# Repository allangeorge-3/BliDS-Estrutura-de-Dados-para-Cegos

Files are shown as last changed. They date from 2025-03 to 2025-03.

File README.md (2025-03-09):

# BlinDS-Estrutura-de-Dados-para-Cegos
Material Educacional de Estrutura de Dados para pessoas com deficiência visual. Contém: Modelos 3D para impressão das peças do material tátil; um Guia de Uso; 2 Sequências Didáticas de apoio ao professor; Familiarização com o material, Pilha e Árvore Binária. Produto da pesquisa de Allan George Bezerra no Mestrado em Tecnologia Educacional - UFC

Produto educacional doMestrado Profissional em Tecnologia Educacional de Allan George Bezerra, da Universidade Federal do Ceará.
Os modelos tridimensionais estãodisponíveis para impressão em uma impressora 3D. O produto da pesquisa passou por 4 versões. A versão 4 do material tátil foiescolhida para seravaliada e foi bem recebida por alunos com deficiência visual e professores de Estrutura de Dados.
Os modelos das versões anteriores também estão disponíveis.

********
IMPRESSÃO DO MATERIAL

Indicado verificar o Guia de Uso do material para saber os componentes básicos de um conjunto para estudo de Estrutura de Dados por pessoas com deficiência visual.
- A base de 8 folhas pode ser montada somente com o encaixe das peças menores. Entretanto, é indicado que essas peças sejam coladas com supercola, para garantir a firmeza durante o uso;
- Fazer o mesmo com a Raiz Conectora, que é formada por 3 peças menores. Colar as 3, formando uma peça única;
- - Pintar os números em relevo (braille e tinta) e as ligações/arestas entre os espaços para encaixes nas bases. Usar uma cor que contrastefortemente com o plano de fundo dessas peças (se o filamento for branco, usar tinta preta, se o filamento for azul-escuro, usar amarelo ou branco, por exemplo).

O link paradissertação do mestrado será disponibilizada após a defesa.

O uso, distribuição e alteração do material é permitido, desde queo link deste projeto seja citado como fonte original.

Contato: allangeorge.3@gmail.com, allangeorge@virtual.ufc.br.
Instagram: allangeorge.3

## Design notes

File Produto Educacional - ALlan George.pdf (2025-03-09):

### 7 O PRODUTO EDUCACIONAL

Complementando os resultados da Etapa 7, este capítulo apresenta a Versão

4 do material tátil, o guia de uso e as duas sequências didáticas. Eles compõem o artefato

que passou pela avaliação descrita no Capítulo 8.

O | produto | está | disponível | no | link:

https://1drv.ms/f/s!Ahwq801rHAGvhtkIIQJfQrJ9wTQ3Ow?e=lKW3Xw

### 7.1 Guia de Uso do Material Tátil

Para apresentar o material tátil ao aluno com DV, ou ao professor, foi elaborado um guia de uso (APÊNDICE F) contemplando uma explicação sobre o seu

objetivo, especificação e descrição das peças, orientação sobre o preparo do material para

iniciar os estudos de ED, e algumas dicas de utilização.

O documento é digital, no formato PDF, e contém algumas imagens para

facilitar ao professor na compreensão do material e seu uso, especialmente se for preciso

acompanhar o discente com DV na familiarização com o material tátil.

### 7.2 Sequências Didáticas

Segundo Zabala (1998, p. 14), temos a seguinte definição para as sequências

didáticas: “são um conjunto de atividades ordenadas, estruturadas e articuladas para a

realização de certos objetivos educacionais, que têm um princípio e um fim conhecidos

tanto pelos professores como pelos alunos.”.

As sequências didáticas desenvolvidas nesta pesquisa também compõem o

artefato. Elas contêm a lista de passos para o desenvolvimento integral das atividades

propostas. O texto se preocupa com a compreensão dos professores que acompanharão a

execução das atividades, e nos alunos com DV que necessitarão de instruções claras para

o entendimento do conteúdo e a manipulação do material tátil.

As sequências são de fácil compreensão, com as etapas descritas em textos

diretos, além de expor claramente seus objetivos e tipo de atividade proposta,

contemplando as fases de planejamento, aplicação e avaliação (Zabala, 1998).

As duas sequências didáticas elaboradas nesta pesquisa podem ser consultadas nos APÊNDICE G E APÊNDICE H, e o detalhamento sobre seu

desenvolvimento estão na subseção a seguir:

### 7.2.1 Especificação das Sequências Didáticas

A fim de facilitar o processo de adaptação das aulas para incluir alunos com

deficiência visual, especialmente para os professores sem experiência ou formação com

educação especial, criou-se um modelo de sequência contendo seções de Planejamento,

Aplicação das atividades e Avaliação. Elas foram exportadas no formato PDF, permitindo

o acesso dos professores e dos alunos que utilizam algum leitor de tela.

A partir dos resultados do questionário com os Professores Consultores, pensou-se em duas sequências didáticas, S1 (APÊNDICE G) e S2 (APÊNDICE H). S1

aborda a familiarização do aluno com DV com o material tátil, propondo que o professor

tenha um contato particular com o estudante, possibilitando que se compreenda mais

sobre os conhecimentos prévios, habilidades e eventuais dificuldades do discente. Além

disso, o discente poderá conhecer o material, e combinar com o professor como será a

comunicação sobre o seu uso, o que é essencial para que o docente possa orientá-lo nas

atividades durante as aulas.

Também há uma atividade com a estrutura de dados Pilha, com dicas de uso

do material para trabalhar estruturas lineares. Isso será útil para preparar o discente no

estudo de vetores, e nas aulas da primeira parte da disciplina de ED.
A sequência S2 (APÊNDICE H) foca na estrutura Árvore Binária,

trabalhando alguns conceitos e a execução de três algoritmos: Inserção, Remoção e Pré-

Ordem. Esta segunda sequência tem mais direcionamentos para o professor, na etapa de

Planejamento. Algumas orientações sobre a verbalização do que é escrito no quadro,

descrição de imagens e comunicação com o aluno com DV, para que haja sincronia entre

a área da estrutura que o professor está apresentando no quadro ou projeções, e a área da

estrutura tateada pelo aluno no material.

Esta segunda sequência permite o uso do material em sua completude, além

trabalhar exigir uma maior interação com o material, na identificação de todas as áreas de

encaixe de números, e a manipulação constante dessas peças e das caixas organizadoras.

A execução dos algoritmos serve para mostrar o potencial do material tátil, visto que

muitas atividades e avaliações analisam o aprendizado do aluno acerca da execução

desses métodos.

O tempo previsto para cada sequência foi sugerido a partir de testes feitos

pelo próprio pesquisador. Ficando 50 minutos para S1, e 110 minutos para S2. Como S2 tem um conteúdo mais extenso, também se propôs dividir a atividade em duas aulas de

50 a 60 minutos.

A aplicação da sequência conta com vários passos, orientando pequenas ações

até que se cumpra uma atividade proposta. Alguns passos contêm dicas de orientação ao

aluno com deficiência visual, inclusive no uso do material tátil.

As avaliações propostas permitem que o discente possa exercitar o conteúdo

abordado, além de permitir que o professor identifique se o aluno conseguiu assimilá-lo.

Por fim, a sequência também aponta o que se espera sobre o aprendizado do aluno, sobre

o que foi abordado.

### 7.3 Versão 4 do Material Tátil

Após as análises dos pontos negativos da Versão 3 do material tátil, pensou-

se em uma nova modelagem que melhorasse alguns requisitos: Estabilidade física do

material, Facilidade de Manuseio, Facilidade de Compreensão e Compatibilidade com

ED.

Melhorando a estabilidade física, facilidade de manuseio e a facilidade de

compreensão, optou-se por abandonar as peças destacáveis para representar as conexões

entre os nós, e trocando seu respectivo espaço de encaixe em baixo relevo, por ligações

fixas em alto relevo. Apesar de possibilitar a presença de conexões entre encaixes e nós

vazios, considerou-se esta opção mais vantajosa do que a instabilidade de peças soltando,

como ocorria na Versão 3.

As ligações entre nós de níveis diferentes ficaram mais longas, ampliando o

comprimento do material, mas ainda permitindo que ele possa ser utilizado em uma

pequena mesa.

A nova base recebeu o nome de “Base de 8 folhas”, pois o último nível

contém oito espaços para encaixe de números em sequência. Ela possui 40cm de largura

e 32,5cm de altura. A seguir, a Figura 21 mostra a nova base:

Figura 21 – Base de 8 Folhas

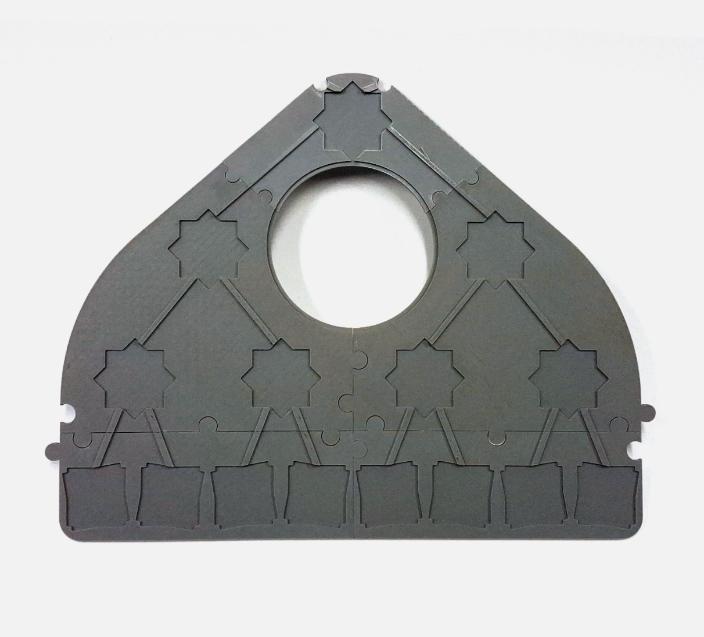
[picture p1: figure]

Fonte: Foto tirada por colaboradores do autor.

O requisito Compatibilidade com Estrutura de Dados foi melhorado com a

criação de uma peça chamada “Raiz Conectora”. Seu papel é servir como uma raiz de

uma árvore binária com 5 níveis. Esta peça pode ser encaixada nos topos de duas bases

de 8 folhas conectadas uma ao lado da outra. A Figura 22 mostra a Raiz Conectora:

Figura 22 – Raiz Conectora

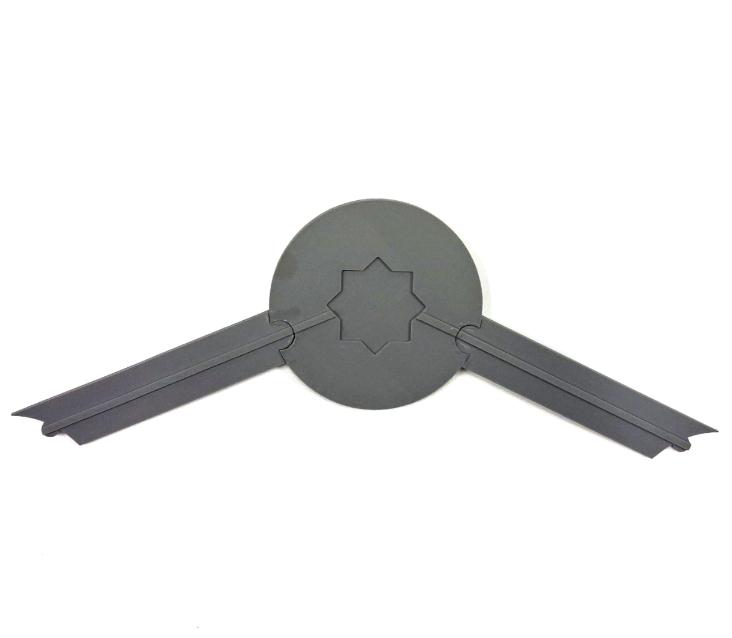
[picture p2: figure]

Fonte: Foto tirada por colaboradores do autor.
A Figura 23 mostra uma grande base formada pela união de duas bases de 8

folhas, uma ao lado da outra, com a raiz conectora no topo das duas. Essa montagem se

chama “Base de 16 folhas”, pois o último nível contém uma sequência de 16 espaços

para encaixe de números, além de ter cinco níveis. Essa montagem completa tem 80cm

de largura e 44,5cm de altura.

Figura 23 – Montagem da Base de 16 Folhas

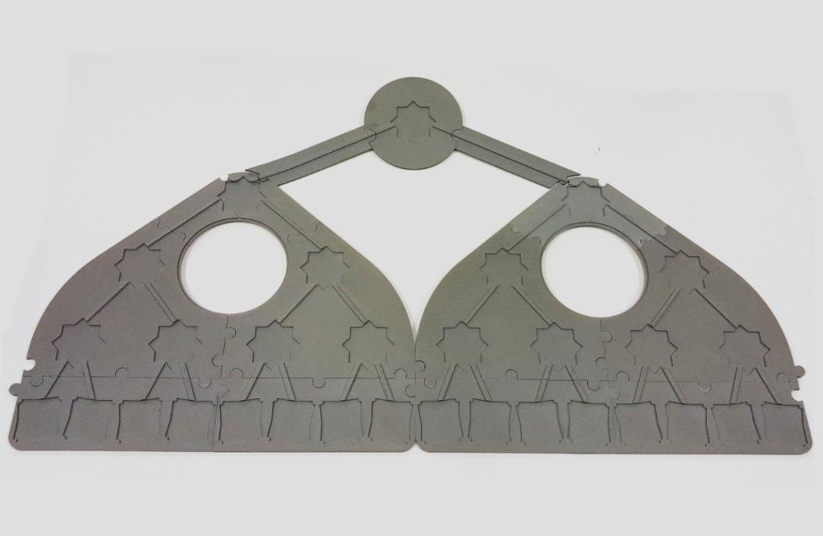
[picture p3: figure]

Fonte: Foto tirada por colaboradores do autor.
Buscando melhorar ainda mais a facilidade de manuseio, com foco na

agilidade do uso do material para realizar as atividades, foram criadas as “Caixas

Organizadoras”. Elas foram pensadas para guardar os números de forma ordenada,

permitindo que o discente com DV encontre a peça numérica rapidamente.

Elas possuem sete espaços para encaixe de números, sendo dois deles um

pouco separados dos demais. O guia de apresentação indica que os números sejam

organizados de cinco em cinco, para que o cálculo mental feito pelo usuário para

identificar a caixa que contém o número procurado seja simples. Os dois espaços

adicionais foram pensados para inserir números repetidos, caso se opte por imprimir

duplicatas.

A Figura 24 mostra algumas caixas organizadoras, algumas com números

encaixados e outras vazias:

Figura 24 – Caixas organizadoras

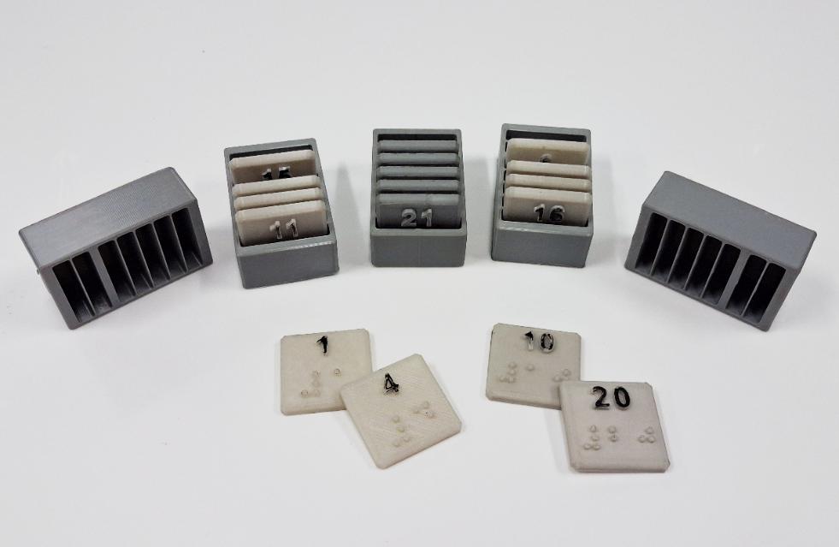
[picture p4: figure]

Fonte: Foto tirada por colaboradores do autor.

Uma última mudança, buscando melhorar o requisito de Compatibilidade

com Estrutura de Dados, foi a mudança no espaço para encaixe dos números. Agora, ela

também permite que uma peça numérica seja encaixada de uma forma alternativa à

anterior. Bastando rotacionar um pouco a peça numérica, é possível encaixá-la em uma

posição diferente. Isso permite que alguns conceitos mais avançados sejam trabalhados, como a pintura dos nós no conteúdo de Árvore Rubro-Negra. Nas entrevistas com os

Alunos Consultores, houve falas sobre a grande dificuldade de compreensão deste

conteúdo, por isso se pensou em adicionar esta funcionalidade ao material.

O guia de uso indica a área da superfície mínima para um uso confortável do

material tátil, já pensando na base completa de 16 folhas, mais um espaço para posicionar

as caixas organizadoras. Uma mesa de 90cm de largura por 50cm de comprimento é o

suficiente para trabalhar com essa estrutura mais completa. Entretanto, se a atividade

puder ser executada somente com uma base de 8 folhas, uma superfície menor pode ser

utilizada. A Figura 25 apresenta uma sugestão de configuração do ambiente de estudo

com o material completo:

Figura 25 – Base de 16 Folhas e as Caixas organizadoras com os números

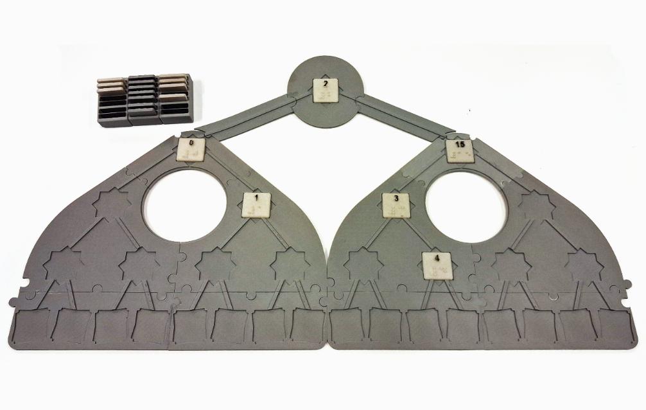
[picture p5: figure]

Fonte: Foto tirada por colaboradores do autor.

A base de 8 folhas é formada por peças menores que se conectam entre si a

partir de encaixes semelhantes aos de um quebra-cabeça, da mesma forma acontece com

a raiz conectora. Pensou-se na versatilidade e na redução da complexidade de replicação,

visto que não se precisaria mais colar essas peças menores. Entretanto, perdeu-se muito

na estabilidade física do material, pois alguns encaixes se soltavam quando as peças eram

movimentadas na superfície, e na facilidade de manuseio, pois a montagem de uma única

base exigia muito tempo e esforço. Por isso, optou-se por colar as peças menores,

transformando-as em componentes maiores, como os já citados.

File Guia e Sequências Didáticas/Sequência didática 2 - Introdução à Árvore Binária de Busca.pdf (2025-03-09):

SEQUÊNCIA DIDÁTICA

DISCIPLINA: Estrutura de Dados

Especificação: Sequência didática utilizando material tátil acessível para pessoas com deficiência visual.

Autor: Allan George Bezerra (allangeorge@virtual.ufc.br )

Instituição: Universidade Federal do Ceará – Mestrado Profissional em Tecnologia Educacional (ppgte.ufc.br)

TEMA: Introdução à Árvore Binária de Busca, usando o material tátil.

CONTEÚDOS TRABALHADOS

- Representação de uma árvore binária no material tátil.
- Trabalhar no desenho da Árvore Binária os conceitos: Raiz, folha, subárvore e altura.
- Execução dos algoritmos de Inserção e Remoção em uma Árvore Binária de Busca.
- Execução do algoritmo para percorrer uma Árvore Binária de Busca em Pré-Ordem.

HABILIDADES

- O aluno aprenderá como utilizar o material tátil para construir a estrutura de dados Árvore Binária de Busca. Ele será orientado sobre a utilização das peças e como tatear o material para compreender o desenho geral da estrutura, assim como os elementos que a compõem.
- O discente saberá identificar alguns conceitos da estrutura de dados Árvore Binária, através do desenho formado no material tátil, tais como: Raíz, nó folha, subárvore e altura.
- O discente aprenderá a construir uma Árvore Binária de Busca utilizando o método de Inserção, e poderá fazer alterações com o método de Remoção de elementos.
- O discente aprenderá a percorrer a árvore utilizando o algoritmo de Pré-Ordem. Ficando apto a percorrer, também, com os algoritmos de Pós-Ordem e Em Ordem.

Tempo da sequência didática

Cerca de 110 minutos.

Caso queira dividir em duas aulas:

Aula 1 – Partes 1 e 2: 60 minutos;

Aula 2 – Partes 3 e 4: 60 minutos.

Materiais necessários para a sequência didática

- Material educacional tátil completo: 5 Caixas organizadoras, Números de 1 a 20, 2 Bases de 8 folhas e Raiz conectora;
- Mesa com superfície de pelo menos 90cm de comprimento e 50cm de largura, aproximadamente;
- Computador equipado com leitor de tela, celular ou outro meio acessível para o aluno fazer anotações ou ler materiais enviados pelo professor.

AULA

Organização

É importante que os alunos com deficiência visual tenham uma mesa com superfície de tamanho suficiente para comportar o material com conforto. Se ele precisar utilizar o computador, é importante que esta mesa esteja bem próxima para que ele possa se mover facilmente e acessar algo.

O material tátil será utilizado para “desenhar” a estrutura de Dados Árvore Binária, da mesma forma que os demais alunos irão desenhar ou observar na lousa os desenhos visuais. Portanto, espera-se que o discente com deficiência visual seja capaz de acompanhar os desenhos pelo material montado, assim como fazer ou responder aos questionamentos feitos durante a aula.

Quando o professor for ministrar os conteúdos propostos nesta Sequência Didática, total ou em partes, é indicado que seja descritivo em suas ações, como:

- Ao escrever na lousa, ditar tudo que está escrevendo;
- Ao apresentar slides, descrever o conteúdo das imagens, e, se importante for, ler o conteúdo projetado;
- Quando for utilizar o desenho de uma Árvore Binária para os exemplos, passe a sequência de números para os alunos com deficiência visual que estarão utilizando o material tátil. Se eles já souberem executar o algoritmo de Inserção, eles saberão construir a árvore a partir da sequência informada. O ideal é que a sequência seja informada ao discente com deficiência visual, antes de desenhar a imagem, ou, caso ela já esteja pronta no slide, você pode preparar um documento digital acessível com antecedência, contendo a lista de sequências numéricas para montagem das árvores. No momento da aula, bastará informar qual a sequência de números que o discente deverá utilizar. Ele poderá acessar o documento de texto pelo celular ou computador.

- Caso o desenho da árvore seja improvisado, ou seja, no momento da aula, o professor poderá executar rapidamente o algoritmo que percorre a árvore em pré-ordem. A sequência numérica resultante poderá ser repassada para o aluno por e-mail ou formato digital que o permita acessar pelo celular ou computador. A árvore binária resultante da inserção dos elementos dessa sequência será igual a que o professor desenhou improvisadamente.
- Quando for apontar um elemento na árvore, além de dizer o valor do nó, é importante descrever sua posição de forma clara e sucinta. Algumas sugestões são: “O nó raiz com valor 18”, “Aqui, no terceiro nível, o quarto nó da esquerda para direita, de valor 10”, “Descendo para a esquerda, temos o nó X” ou “No nível 4 da árvore, o segundo nó, de valor 2, é um nó folha” (se já acertar com o aluno que a contagem de nós é da esquerda para direita, não precisará informar que se deve contar nessa direção, pois já fica subtendido).

Introdução

A aula ocorrerá normalmente, para toda a turma, incluindo o discente com deficiência visual. Ele já deve estar posicionado com o material montado. O professor deve verificar se o aluno precisará montar a base completa de 16 folhas, ou se apenas uma Base de 8 folhas já é o suficiente para todos os exemplos a serem trabalhados na aula.

Com a aula descritiva, tendo as informações passadas ao aluno com deficiência visual antecipadamente, e dando um acesso fácil e ágil ao dispositivo preferível por ele (celular, computador, notebook etc.), espera-se que a aula siga sem a necessidade de mais adaptações, além das citadas anteriormente.

Caso o professor organize o seu cronograma de aulas de forma incompatível a esta sequência didática, ele pode fazer uma divisão dos conteúdos, trabalhando as partes 1 e 2 em uma aula, e as partes 3 e 4 em um outro momento.

Desenvolvimento

Parte 1: Construindo uma Árvore Binária

1- Construa uma Árvore Binária no material tátil.

O discente deve colocar as peças numéricas nos encaixes na Base de 8 folhas. Por ser uma peça mais simples e compacta, o entendimento do desenho da estrutura será mais fácil. Aproveite para desenhar na lousa a mesma estrutura de árvore que o discente com deficiência visual está montando na base.

O encaixe deve seguir uma ordem: Iniciando pelo encaixe do primeiro nível, depois os encaixes no segundo nível. Quando preencher todos os espaços, o discente poderá passar para o próximo nível. O último nível (nível 4) não precisa ser totalmente preenchido.

2- Compreenda o desenho de uma Árvore Binária.

O discente deve utilizar as mãos para sentir as peças encaixadas, e perceber as ligações entre um número e o outro encaixado logo abaixo. Se quiser, pode usar uma das mãos para percorrer, e a outra para segurar a base através do círculo vazado, caso queira manter o material mais firme.

O professor pode verbalizar todos os elementos da árvore, informando o caminho que está percorrendo ("A raiz é o número X, descendo pela esquerda temos o nó Y, indo a esquerda novamente, temos o número Z"). Outra opção é pedir que o próprio aluno com deficiência visual verbalize os nós visitados e os caminhos que vai percorrendo, conforme a orientação do professor (“Segue para o nó raiz. Qual o valor dele? Descendo pelo caminho a esquerda, qual o valor desse nó?” etc.).

Cada número encaixado é um nó da árvore, ignore os encaixes vazios. As linhas em alto relevo são as ligações entre nós de níveis diferentes.

3- Modifique o desenho da Árvore Binária

O discente deve remover alguns nós da árvore construída no material. A remoção pode ser feita de forma aleatória, ou sob orientação do professor.

Se o professor preferir, ele pode orientar o aluno com deficiência visual a escolher os elementos a serem removidos, e pedir que ele vá informando o caminho que vai fazendo, ou o próprio professor pode ir informando isso para que o aluno vá sempre acompanhando e confirmando o caminho percorrido, já que o desenho trabalhado na lousa é o mesmo que o do material tátil.

Um nó só pode permanecer na base, caso haja uma conexão com outro nó posicionado em um nível acima dele. Caso contrário, ele deve ser removido. Lembre-se que toda peça removida deve ser guardada na sua respectiva caixa organizadora, de forma ordenada, para facilitar sua busca nas próximas atividades.

Após a remoção, o discente deve percorrer a estrutura formada com as mãos. A exploração deve começar pelo único nó no primeiro nível, e depois descendo pelas ligações que conectam a outros nós em níveis mais baixos.

O discente deve compreender a estrutura como um todo para perceber como ficou o seu desenho, ignorando os espaços de encaixe vazios.

Esse momento, também, pode ser guiado de forma verbal pelo professor ou pelo próprio aluno com deficiência visual.

Parte 2: Conceitos básicos de uma Árvore Binária

4- Identifique os Nós e a Raíz da Árvore Binária construída

Primeiramente, caso tenha dificuldades com o desenho restante da árvore anterior, o discente poderá reposicionar os nós nos espaços vazios, deixando todos os níveis utilizados preenchidos.

Cada elemento numérico da árvore é um nó.

O nó chamado Raiz é o primeiro nó que inicia a Árvore Binária. Ele fica sozinho no primeiro nível. Identifique este nó.

5- Identifique os Filhos a Esquerda e os Filhos a Direita.

Cada nó tem duas ligações que os conectam a um espaço de encaixe no nível logo abaixo dele. Uma ligação para a esquerda e outra para a direita. Partindo da raiz, uma ligação direcionada para a esquerda irá conectá-la a outro nó, no nível logo abaixo. Esse é o Nó Filho a Esquerda, ou somente o seu Filho a Esquerda. Partindo da raiz novamente, seguindo agora pela outra ligação, a qual se encaminha pela direita, chegamos ao Nó Filho a Direita da raiz, ou somente Filho a Direita da raiz.

Percorra os nós da árvore, e identifique o filho a esquerda e o filho a direita de cada um.

6- Identifique o que é um Nó Pai.

Excetuando a raiz, todos os nós são filhos a esquerda ou à direita de um nó em nível superior. Escolha um nó na árvore, que não seja a raiz. A ligação que sai dele para o nível logo acima, o levará ao seu Nó Pai.

7- Identifique as Folhas.

Percorra a árvore com o seu tato e procure por nós que não tem nenhum filho, nem a esquerda, nem a direita. Provavelmente eles estarão nos níveis mais baixos, podendo haver exceções, a depender de como a árvore está desenhada. Os nós que não possuem nenhum filho são chamados de Nós Folha, ou simplesmente Folhas. Identifique todas as folhas da árvore.

8- Identifique uma subárvore.

O conjunto formado por um nó e todos os outros acessíveis a partir dele, seguindo até às folhas, é uma subárvore da árvore principal.

Escolha um nó qualquer da árvore, que não seja a raiz. Percorra todos os nós abaixo dele, até chegar às folhas. Esse nó é a raiz de uma subárvore da árvore principal. Tente identificar mais subárvores.

9- Calcule a altura da árvore.

Para calcular a altura de uma árvore, primeiramente é necessário saber contabilizar a distância entre dois nós. A distância entre dois nós é a quantidade de ligações percorridas para sair de um até chegar ao outro.

A Altura de um nó qualquer, é a distância dele até a folha do nível mais baixo. Lembrando que as ligações percorridas para calcular a altura, devem sempre seguir descendo pelos nós filhos. Escolha alguns nós da árvore e calcula a altura deles.

A altura da árvore é a altura de sua raiz. Ou seja, a distância da raiz até o nó folha de nível mais baixo. Calcule a altura da árvore montada no material tátil.

Escolha algumas subárvores e calcule a altura delas.

Após concluir esta parte da sequência e compreender alguns conceitos sobre Árvore Binária, esvazie a base de todos os nós, lembrando de guardar todos os números de forma ordenada em suas respectivas caixas organizadoras.

Parte 3: Construindo uma Árvore Binária de Busca

10- Construa uma Árvore Binária de Busca, inserindo os elementos: 10, 13, 11, 6, 12, 22, 9, 20, 23, 8, 5.

Uma Árvore Binária de Busca é uma Árvore Binária que segue algumas regras para se manter ordenada. Para isso, ela tem a característica de que todo elemento adicionado a ela já é inserido de forma ordenada. Para isso, o Algoritmo de Inserção de qualquer elemento segue a seguinte regra:

O elemento é inserido a partir da raiz;

Se o espaço estiver vazio, adicione o elemento naquele espaço;

Se não estiver vazio, verifique o seguinte:

Se o número a ser inserido for menor, siga para o espaço de encaixe a esquerda.

Se o número a ser inserido for maior, siga para o espaço de encaixe a direita.

Repita esses procedimentos até encontrar um espaço vazio para o novo elemento ser encaixado na base.

FIM

Execute esse algoritmo para inserir todos os números da sequência indicada neste passo.

O professor pode verificar se a árvore resultante, após a inserção de todos os nós, está correta. Isso irá assegurar que o discente acompanhará os próximos passos de forma sincronizada à árvore mostrada na lousa ou projeção, pelo professor.

O discente pode tatear a árvore construída para compreender sua forma, identificar a raiz, as folhas, calcular a altura da árvore etc.

11- Remova os elementos 8, 11, 13.

Da mesma forma que a Inserção, a Remoção de elementos não pode mudar a característica de uma árvore ordenada da estrutura. Assim, quando um elemento é removido, a árvore deve continuar ordenada, seguindo a regra de que, para cada nó, os elementos menores ficam a sua esquerda, e os elementos maiores ficam a sua direita.

Para remover os elementos, siga o Algoritmo de Remoção:

Se o nó removido for uma folha, basta deletá-lo e transformá-lo em nulo (encaixe vazio).

Se o nó removido tiver apenas um filho, ele será deletado e o seu filho fica no seu lugar.

Se o nó removido tiver dois filhos

Busca-se o sucessor.

O sucessor é o nó mais à esquerda do filho à direita do nó removido. (Basta dar um passo a direita, e depois seguir somente para a esquerda até não ter mais filho a esquerda. Esse nó será o sucessor).

Mova o sucessor para o lugar do nó removido.

Se o sucessor não tiver filhos, então basta deletá-lo.

Se o sucessor tiver um filho (que neste caso seria à direita), basta agir como se tivesse ocorrido uma operação de remoção no sucessor, ou seja, o nó filho do sucessor ficará no seu lugar.

FIM

Use o algoritmo de remoção para remover os elementos solicitados.

O professor pode verificar se a árvore resultante, após as remoções, está correta.

O discente pode tatear a árvore construída para compreender sua forma, identificar a raiz, as folhas, calcular a altura da árvore etc.

Parte 4: Percorrendo uma Árvore Binária de Busca

12- Percorra a árvore usando o algoritmo de Pré-Ordem.

Existem três algoritmos para percorrer todos os nós de uma árvore binária, e tendo a sequência de todos os seus valores em uma sequência resultante. Os algoritmos são: Pré-Ordem, Pós-Ordem e Em Ordem.

Ao percorrer uma árvore binária, nenhum nós é removido ou inserido. Apenas há o registro os valores visitados durante a execução do algoritmo, formando uma sequência de números, na ordem em que os elementos foram visitados.

O Algoritmo de Pré-Ordem registra o valor dos nós visitados seguindo a seguinte regra: Registra-se a Raiz, registra-se o filho a esquerda e registra-se o filho a direita.

Para cada nó analisado/visitado, é preciso tratá-lo como uma nova árvore ou subárvore, dessa forma, um filho a esquerda, que é visitado, passa a ser considerado uma raiz de uma subárvore, e o seu valor já entra para a sequência de números. Quando não houver mais filhos a esquerda, aí o filho a direita é analisado, para somente depois subir para analisar os filhos a direita do pai dessa subárvore. Isso ocorre por ser um algoritmo recursivo.

Algoritmo Pré-Ordem:

Inicia analisando a Raiz da árvore.

Registrar valor da raiz;

Desce para filho a esquerda;

Se houver um nó, trata-o como nova raiz, e repete o processo do início;

Se estiver vazio, volta para o nó pai e desce para o filho da direita;

Se houver um nó, trata-o como nova raiz e repete o processo desde o início;

Se estiver vazio, sobe até um nó pai cujo tenha um filho que não foi analisado e registrado na sequência e desce para o seu filho à direita, trata esse filho como nova raiz e repete o processo do início.

Se voltar para a raiz da árvore principal, e já tiver analisado o seu filho a esquerda e a direita, então todos os elementos foram registrados na sequência.

FIM

Em resumo, a ordem de visita dos nós ao percorrer uma árvore é:

Pré-Ordem: Raiz, Filho a Esquerda, Filho a Direita.

Em Ordem: Filho a esquerda, Raiz, Filho a direita.

Pós-Ordem: Filho a esquerda, Filho a direita, Raiz.

O discente deve executar o algoritmo de pré-ordem e anotar a sequência de números resultante do processo, no local que preferir, celular, computador etc.

Conclusão

O professor deve analisar os resultados da atividade e o desempenho do aluno na utilização do material e compreensão do conteúdo. Se for fazer alguma correção, e tiver dificuldades de orientar verbalmente, pode perguntar, ou já ter combinado com o aluno antes, se pode tocar a mão dele para conduzir o toque até o local correto do material que deseja tecer alguma explicação. Em geral, apenas a orientação com as coordenadas será o suficiente (“O terceiro nível, o quarto nó, de valor X”).

Esta sequência pode ser muito longa para apenas uma aula, a depender do nível dos alunos, então pode ser necessário dividir as atividades em duas aulas, deixando a execução dos algoritmos para um segundo momento, dando tempo para o aluno exercitar o uso do material na montagem de uma árvore e os conceitos trabalhados.

O professor pode preparar algumas sequências de números para o discente com deficiência visual montar algumas árvores binárias em casa. Se ela tiver uma altura igual a 4 (quinto nível do material) ele poderá montar a base de 16 folhas, que permite uma árvore desta altura. Indica-se, sempre que possível, trabalhar árvores com altura até 3, para agilizar o uso de um material mais compacto. Entretanto, não é preciso prejudicar a abordagem do conteúdo por esse motivo, se for ´vantajoso para o aprendizado trabalhar uma árvore maior, então deve-se aproveitar o potencial total do material tátil.

O professor pode solicitar que o discente também execute os três algoritmos para percorrer uma árvore binária em casa, enviando posteriormente a sequência de números resultante.

O feedback do discente com deficiência visual é importante. Então, o professor pode perguntar, ao final da aula, se há alguma mudança na metodologia que possa melhorar a execução das aulas ou atividades propostas, como passar os números para montagem da estrutura com antecedência, pedir que o material já seja montado antes que a aula inicie, ser mais descritivo durante a explicação etc.

Avaliação

Se tiver passado exercício de casa, o professor deve avaliar as sequências enviadas pelo aluno. Se necessário, pode pedir filmagens ou fotografias durante o momento de mudanças na estrutura do material, durante a execução dos algoritmos.

O professor deve verificar as respostas dadas pelo aluno com deficiência visual e verificar, no caso de erros, se isso ocorreu pela falta de compreensão do conteúdo, ou se foi um manuseio equivocado do material ou montagem errada da estrutura.

Verifique se o aluno respondeu as atividades de sala ou de casa de forma correta, sabendo identificar os elementos das árvores construídas com as sequências de números disponibilizadas, e se os algoritmos foram executados corretamente.

FINALIZAÇÃO DA SEQUÊNCIA

O aluno deve conseguir identificar todos os elementos de uma Árvore Binária (Raiz, Folha, filho a esquerda, subárvore etc.). O professor pode verificar isso através das respostas dos exercícios enviadas por e-mail, por exemplo.

Da mesma forma, o discente com deficiência visual deve saber executar os algoritmos de inserção, remoção e para percorrer a Árvore Binária de Busca. Se possível, o discente pode fazer registros do manuseio do material, através de fotos ou vídeos, se ele conseguir. Caso contrário, o professor pode reservar um momento para pedir que o discente revise alguns conceitos sob sua observância, para verificar se ele está absorvendo o conteúdo.

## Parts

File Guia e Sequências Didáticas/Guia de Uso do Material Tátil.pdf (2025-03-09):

GUIA DE USO DO MATERIAL TÁTIL

INTRODUÇÃO

Este Material Educacional Tátil foi desenvolvido para pessoas com deficiência visual que desejam estudar o conteúdo de Estrutura de Dados, especialmente Árvore Binária. Algumas estruturas de dados lineares também podem ser trabalhadas, como Pilha, Fila, Lista Encadeada etc.

Desenvolvido na pesquisa do Mestrado Profissional em Tecnologia Educacional de Allan George Bezerra, sob orientação do Prof. Dr. Windson Viana de Carvalho, o material foi produzido em impressoras 3D, e os modelos tridimensionais estão disponíveis ao público no LINK.

COMPONENTES

Se o usuário preferir, pode imprimir uma quantidade maior de peças, mas o conjunto básico é formado pelos seguintes componentes: 6 caixas organizadoras, 30 peças de números, 2 bases de 8 folhas (ou de 4 níveis) e uma raiz conectora.

Detalhando cada um dos componentes temos:

A) Caixa organizadora: O conjunto básico possui 6 caixas organizadoras de números, em formato de paralelepípedo. Uma de suas faces possui 7 espaços para encaixe de peças numéricas. Perceba que 2 espaços são um pouco separado dos outros 5;

Figura 1 – Caixas organizadoras.

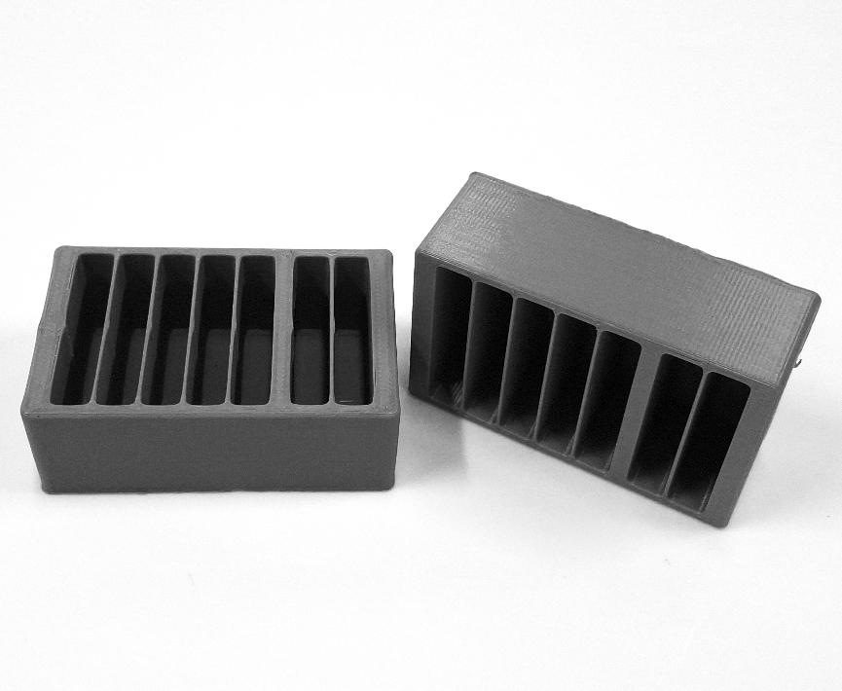
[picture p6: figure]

Fonte: Foto tirada por colaboradores do pesquisador.

B) Peças Numéricas (Números): O conjunto possui 30 peças em formato de quadrado achatado. Em uma das faces há duas inscrições em alto relevo: Um número escrito em braille na parte inferior, e o mesmo número em tinta, logo acima;

Figura 2 – Peças numéricas.

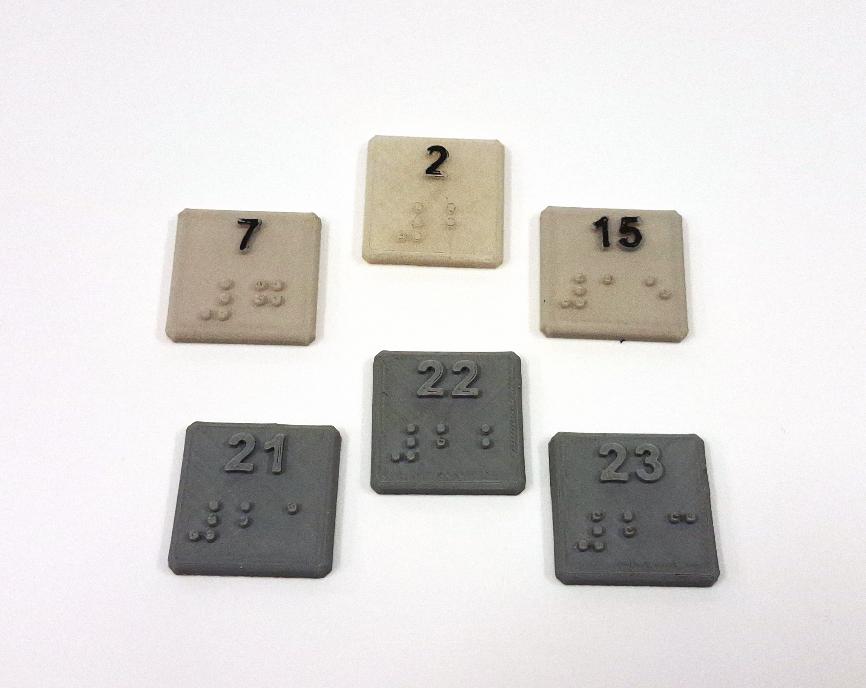
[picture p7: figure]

Fonte: Foto tirada por colaboradores do pesquisador.

C) Base de 8 folhas, ou Base de 4 níveis: Existem duas grandes peças semelhantes a um triângulo, com um círculo vazado próximo ao centro. Cada uma possui 15 espaços para encaixe das peças numéricas, em baixo relevo. No topo da peça existe um único espaço de encaixe, acima do círculo vazado. De cada espaço de encaixe de números saem duas ligações em alto relevo, conectando aos encaixes do próximo nível. O primeiro nível tem apenas um espaço, o segundo nível possui dois, o terceiro tem quatro e o quarto nível possui oito espaços para encaixe.

Figura 3 – Base de 8 folhas.

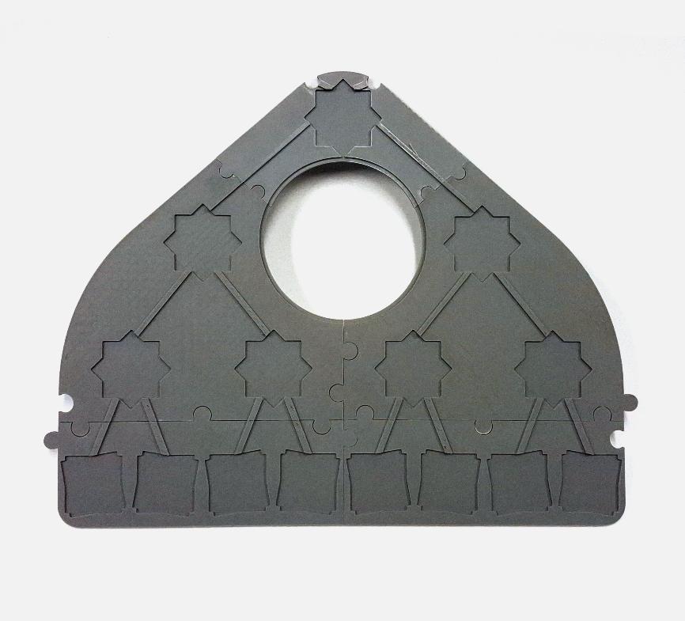
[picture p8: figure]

Fonte: Foto tirada por colaboradores do pesquisador.

D) Raiz conectora: A última peça se assemelha a um círculo, o qual possui apenas um espaço de encaixe no centro. Dele saem duas ligações em alto relevo. Sua posição correta deve se assemelhar a um acento circunflexo, com as ligações descendo, e o círculo no topo. Esta peça servirá para conectar o topo das duas bases de 8 folhas.

Figura 4 – Raiz Conectora.

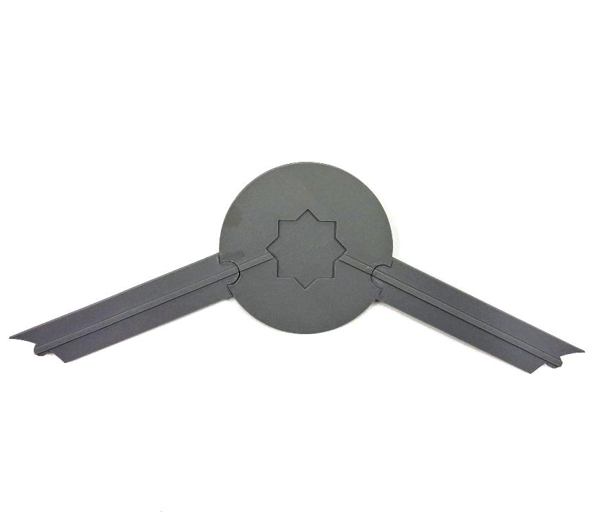
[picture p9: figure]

Fonte: Foto tirada por colaboradores do pesquisador.

PREPARO DO AMBIENTE

1) Em uma superfície de pelo menos 90cm de comprimento por 50cm de largura, posicione as duas Bases de 8 Folhas uma ao lado da outra. Existem duas peças desta mesma base, pois elas podem ser conectadas, através de uma peça de encaixe, semelhante a um conector de peças de quebra-cabeça, na altura do último nível, ficando uma ao lado da outra. Isso gerará uma sequência de 16 encaixes no último nível;
2) Acima das duas bases encaixadas, posicione a Raiz Conectora. As duas ligações que descem do centro circular devem encaixar, cada uma, na parte superior de cada base. A Raiz conectora passará a ser o primeiro nível de uma peça bem maior, formada por ela e as duas bases. O Nível 5 é adicionado, contendo 16 espaços para encaixe, essa formação se chama Base de 16 folhas, ou Base de 5 níveis.

Figura 5 – Base de 16 Folhas.

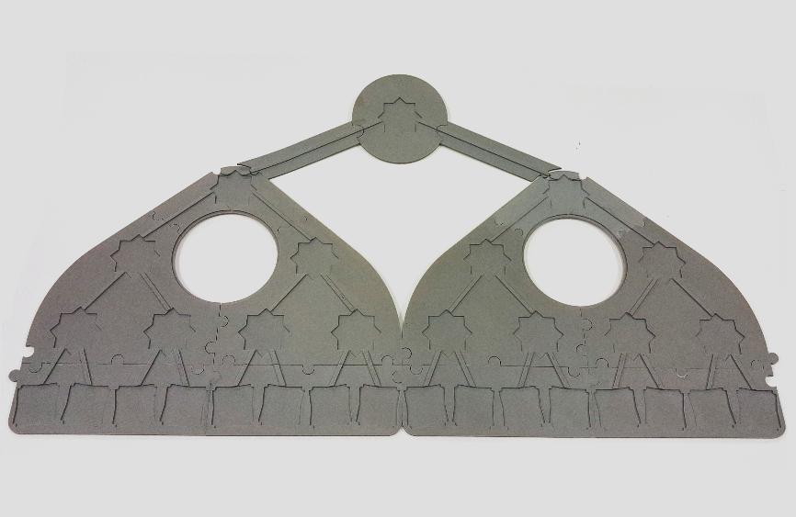
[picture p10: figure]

Fonte: Foto tirada por colaboradores do pesquisador.

3) Posicione as Caixas Organizadoras uma ao lado da outra, ou em duas fileiras de 3 caixas. Apesar de conter 7 espaços para números, indica-se usar apenas 5, deixando os outros 2 livres para duplicatas, por exemplo. A contagem de números 5 a 5 facilita a busca e a guarda dos números;
4) Pegue cada uma das Peças Numéricas e as coloque nos espaços das caixas organizadoras, de forma ordenada. A primeira caixa deve guardar os números de 0 a 4, ocupando 5 espaços no total. Da mesma forma, as caixas seguintes devem guardar cinco números, deixando dois espaços para guardar duplicatas, ficando assim: Segunda caixa, de 5 a 9, terceira caixa de 10 a 14, quarta caixa de 15 a 19, quinta caixa de 20 a 24 e a sexta caixa de 25 a 29.

Figura 6 – Ambiente completo preparado.

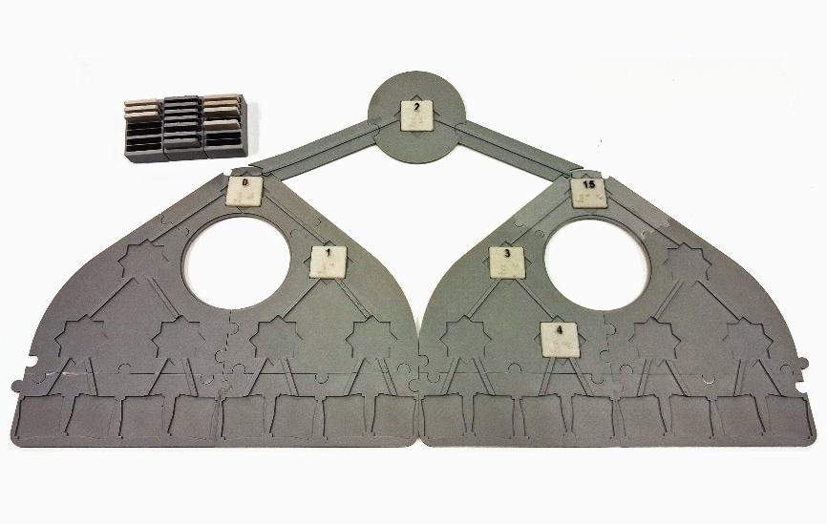
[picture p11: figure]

Fonte: Foto tirada por colaboradores do pesquisador.

DICAS DE USO

1) Só monte a base de 16 folhas caso a atividade de estudo exija uma estrutura que utilize os 5 níveis, caso contrário, é mais prático utilizar somente uma base de 8 folhas;
2) Sempre que retirar um número da base, guarde-o na sua respectiva caixa organizadora, de forma ordenada. A organização ordenada dos números é essencial para dar mais agilidade na manipulação do material durante as atividades;
3) Se não souber ler em braille, pode utilizar o tato para ler o número em alto relevo, escrito em tinta. Entretanto, a leitura braille é bem mais imediata, portanto, indica-se tentar aprender o básico dessa forma de escrita, para tentar decorar os números conforme vá utilizando o material. Ao ler as peças numéricas através do braille, se tem mais certeza do número escrito, e a compreensão é bem mais fluida;
4) Se quiser representar números pintados de outra cor, como na Árvore Rubro-Negra, pode encaixar a peça numérica um pouco rotacionada. Os encaixes possuem estrutura para isso;
5) Se quiser um pouco mais de estabilidade, pode posicionar uma das mãos no círculo vazado, na base de 8 folhas, para dar mais firmeza enquanto tateia com a outra mão;
6) Ao montar o ambiente, deve-se posicionar as caixas organizadoras um pouco mais distante do utilizador. Isso evitará que alguns movimentos com os braços esbarrem nas caixas, as derrubando no chão;
7) Apesar de focar em atividades com a estrutura Árvore Binária, é possível escolher algumas áreas das bases para o estudo de estruturas lineares, como vetores, pilhas, filas ou listas encadeadas, por exemplo. O último nível da base de 8 folhas tem 8 espaços para encaixe, um ao lado do outro, semelhante a uma representação gráfica de um vetor. Estruturas maiores podem ser feitas usando a base de 16 folhas, ou somente assumindo que os encaixes de um nível são da sequência de encaixes do nível anterior, por exemplo.
Esse guia é uma sugestão para um conjunto básico. Portanto, mais ou menos peças podem ser impressas. As bases de 8 folhas são formadas pela colagem de outras peças menores. Então, a impressão individual desses componentes menores pode ser feita para atender algumas necessidades mais específicas.

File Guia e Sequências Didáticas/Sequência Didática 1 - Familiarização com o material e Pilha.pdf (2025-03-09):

SEQUÊNCIA DIDÁTICA

DISCIPLINA: Estrutura de Dados

Especificação: Sequência didática utilizando material tátil acessível para pessoas com deficiência visual.

Autor: Allan George Bezerra (allangeorge@virtual.ufc.br )

Instituição: Universidade Federal do Ceará – Mestrado Profissional em Tecnologia Educacional (ppgte.ufc.br)

TEMA: Familiarização com o material educacional tátil usando Pilha

CONTEÚDOS TRABALHADOS

- Apresentação geral do material tátil e suas peças
- Orientação de uso das peças numéricas
- Preparação do material tátil para execução das atividades
- Simulação dos conceitos básicos de pilha

HABILIDADES

O aluno conseguirá identificar as peças que compõe o material tátil: As 2 bases, a raiz de conexão, os números e as caixas organizadoras. Aprenderá como organizar o material e deixá-lo preparado para realizar as atividades da disciplina que envolvem estruturas de dados.

O aluno compreenderá como usar o material para trabalhar a estrutura de dados Pilha, identificando alguns conceitos básicos, assim como a execução da ação de Empilhar e Desempilhar.

Tempo da sequência didática

Cerca de 60 minutos.

Materiais necessários para a sequência didática

- Material educacional tátil completo: 5 Caixas organizadoras, Números de 1 a 20, 2 Bases de 8 folhas e Raiz conectora;
- Mesa com superfície de pelo menos 90cm de comprimento e 50cm de largura, aproximadamente;
- Computador equipado com leitor de tela, celular ou outro meio acessível para o aluno fazer anotações ou ler materiais enviados pelo professor.

AULA

Organização

A atividade pode ser realizada individualmente pelo próprio aluno, em seu ambiente de estudo, ou com a mediação do professor. Caso o discente execute as atividades de forma individual, ele pode simplesmente seguir os passos propostos nesta sequência, como se fosse um manual para conhecer o material, contendo sugestões de práticas para seu uso.

Se o professor identificar a necessidade de acompanhar o aluno nesta atividade, deve-se preparar um momento exclusivo com ele, na sala de aula. Indica-se utilizar cerca de 60 minutos no fim de uma das primeiras aulas, preferencialmente antes de trabalhar alguma estrutura de dados.

Introdução

Em uma das primeiras aulas da disciplina, antes de trabalhar com foco em uma estrutura de dados ou vetores, deve-se reservar os últimos 60 minutos para apresentar o material de forma individual com o aluno. Se preferir, o professor pode realizar essa atividade exclusiva nos primeiros 60 minutos de aula, combinando com o restante da turma anteriormente, para que cheguem um pouco depois. Caso haja possibilidade, esta atividade pode ser realizada em outro momento, até mesmo em um ambiente diferente da sala de aula. Entretanto, é preciso garantir que haja uma mesa ou móvel com superfície discreta, porém com área suficiente para posicionar o material tátil na sala onde as aulas irão acontecer.

O professor deve conversar com o aluno, preferencialmente antes da aula, podendo ser presencialmente ou por e-mail, para compreender suas demandas, possibilidades e dificuldades. Isso poderá facilitar a decisão de permitir que ele realize a atividade sozinho, no ambiente que escolher, ou se uma mediação será necessária.

Desenvolvimento

Parte 1: Conhecendo o material

1- Apresente a caixa do material ao aluno.

O discente deve estar posicionado à mesa que ficará durante as aulas, quando precisar utilizar o material tátil, ou no seu ambiente de estudos.

O discente deve abrir a caixa e ter ciência de quantas e quais peças estão disponíveis.

São elas: 5 caixas organizadoras, 20 peças de números, 2 bases de 4 níveis e uma raiz conectora.

2- Oriente o discente na identificação de cada peça da caixa.

Peça para o discente retirar cada peça da caixa, uma a uma, identificando seu nome para que ele faça o reconhecimento. O professor pode dizer o nome da peça que ele deve pegar, descrevendo como ela é, junto a sua função.

Segue a sugestão de ordem para apreciação:

A) Caixa organizadora: na caixa há 5 caixas organizadoras de números, em formato de paralelepípedo. Uma de suas faces possui 7 espaços para encaixe dos números. Perceba que 2 espaços são um pouco separado dos demais 5;
B) Números: Você encontrará 20 peças semelhantes a um quadrado achatado. Em uma das faces de cada peça existe uma inscrição em alto relevo de um número escrito em braille, na parte inferior, e sua representação em tinta, logo acima.
C) Base de 8 folhas, ou Base de 4 níveis: Existem 2 grandes peças que possuem um formato próximo a um triângulo, com um círculo vazado próximo ao centro. Cada uma possui 15 espaços em baixo relevo. O topo da peça existe um único espaço de encaixe, acima do círculo vazado. De cada espaço de encaixe saem duas ligações em alto relevo para outros dois espaços em baixo relevo. O primeiro nível tem apenas um espaço, o segundo nível possui dois, o terceiro tem quatro e o quarto nível possui oito espaços para encaixe. Esta peça é uma base para trabalhar as estruturas estudadas na disciplina. Os números podem ser encaixados nesses espaços em baixo relevo, mas não encaixe nada neste momento. Ela pode ser chamada de Base de 4 níveis, os quais foram descritos, ou de Base de 8 folhas, por possuir oito espaços para encaixe no último nível.

Existem duas peças desta mesma base, pois elas podem ser conectadas, através de uma peça de encaixe, semelhante a um conector de peças de quebra-cabeça, na altura do último nível, ficando uma ao lado da outra. Isso gerará uma sequência de 16 encaixes no último nível.

D) Raiz conectora: A última peça se assemelha a um círculo, o qual possui apenas um espaço de encaixe no centro. Dele saem duas ligações em alto relevo. Sua posição correta deve se assemelhar a um acento circunflexo, com as ligações descendo, e o círculo no topo. Esta peça servirá para conectar o topo das duas bases de 8 folhas. Se as duas bases de 8 folhas ficarem conectadas uma ao lado da outra, encaixadas pela conexão nas laterais do último nível, a Raiz Conectora poderá ser utilizada para transformar toda a peça em uma nova base de 5 níveis, ou uma Base de 16 folhas. Para isso, a Raiz Conectora deve ser posicionada acima das duas bases de 8 folhas já encaixadas. Cada ligação que sair do círculo principal deve ser encaixada no topo de cada uma das duas bases triangulares. Perceba que há um espaço para encaixe.

Parte 2: Preparando o ambiente

3- Identifique os números escritos em alto relevo.

Todas as peças numéricas possuem um número escrito em alto relevo. A escrita em braille fica na parte inferior da peça, e a escrita em tinta fica na parte superior. Caso não saiba ler em braille, pode tentar identificar as peças pela escrita em tinta. O reconhecimento pode não ser tão imediato quanto o braille, mas com a prática, a percepção pode ficar cada vez mais rápida.

DICA: Um caractere braille é formado por 6 pontos. Um número em braille sempre inicia por um caractere que identificará que o que virá escrito a seguir, trata-se de um número e não uma letra ou palavra. Por isso, o primeiro caractere braille em todas as peças é o mesmo, semelhante a letra “L” ao contrário. O aluno pode memorizar os números em braille, sempre que perceber a escrita em tinta, pois a leitura do braille é imediata e aumentará muito a agilidade no reconhecimento das peças. Indica-se ao aluno buscar algum vídeo ou curso rápido básico de braille, para saber como funciona a escrita, para facilitar a memorização.

4- Organize todos os números nas caixas organizadoras, de forma ordenada.

Cada Caixa Organizadora possui 5 espaços para encaixe dos números, e mais 2 espaços, discretamente afastados dos demais, para guardar mais duas peças numéricas. Encaixe, de forma ordenada, todos os números, cinco a cinco, nas Caixas organizadoras. Os dois espaços adicionais são para inserir números repetidos, caso haja algum.

A primeira caixa terá 6 números, pois iniciará com o zero. Portanto, ela guardará os números de 0 a 5, deixando um espaço sobrando para duplicatas.

Organizando os números de cinco em cinco, em ordem crescente, o aluno poderá encontrar rapidamente a peça com o número que ele precisa para montar uma estrutura. Quando ele não precisar mais do número, deverá guardar na posição correta. A organização permite que o discente tenha grande agilidade ao manusear o material.

Deixe as Caixas Organizadoras uma ao lado da outra, de forma crescente. A primeira irá conter os números de 0 a 5, a segunda de 6 a 10, a terceira de 11 a 15, e assim por diante.

5- Monte a grande Base de 16 folhas

Pegue uma Base de 8 folhas e posicione sobre a superfície da mesa. Logo em seguida, pegue a segunda base e faça o mesmo, deixando-a ao lado da primeira. Tente conectar as duas, através dos encaixes posicionados na lateral da última fileira com os 8 espaços em baixo relevo.

Após conseguir encaixar, pegue a Raiz Conectora, e posicione na superfície da mesa, acima das bases que você acabou de conectar. Conecte cada ponta de ligação à parte superior de cada uma das bases de 8 folhas. Verifique se ficou bem encaixado.

Ao final, a Raiz Conectora será o primeiro nível, com apenas um encaixe, e a cada nível abaixo, teremos a quantidade de espaços para encaixe de peças numéricas duplicada, até chegar ao último com 16 espaços.

Parte 3: Trabalhando com a estrutura de dados Pilha

6- Explicação sobre a estrutura de dados Pilha.

O aluno deve ser informado basicamente sobre a estrutura de dados Pilha. Utilize assimilações que facilite a mentalização do seu funcionamento, como a montagem de uma pilha de pratos, na qual um primeiro prato é colocado sobre a mesa, e os pratos seguintes são colocados sobre o último prato inserido. A inserção de um elemento na pilha, neste caso um prato, é a execução de um método chamado Push.

No mesmo exemplo, se precisar remover um prato da pilha, deverá começar a remoção pelo elemento que estiver no topo. A remoção deverá ocorrer uma a uma, até chegar no prato que deseja alcançar. O método de remoção de um elemento da pilha se chama Pop.

7- Escolha uma área para montar uma Pilha de 11 elementos no material tátil.

O aluno deverá montar uma pilha de 11 elementos no material tátil. Os elementos serão identificados por números.

Para facilitar, pode-se utilizar apenas um vetor com 11 espaços, e cada espaço poderá ser preenchido por um elemento da pilha. Dessa forma, o estudante deve identificar no material tátil uma área que permita trabalhar com pelo menos 11 números a serem encaixados em sequência, um ao lado do outro.

8- Execute o método Push para os elementos: 2, 6, 1, 15, 0, 12, 18, 21, 11, 3 e 23.

Pegue os números, um a um, nas caixas organizadoras, e os encaixe nos espaços em baixo relevo da base, na área selecionada. Escolha um espaço para ser o início da pilha, e vá inserindo os números seguintes ao lado, até que o último elemento seja adicionado.

9- Identifique o elemento do topo da Pilha.

Registre, no celular ou em anotação no computador, o elemento do topo da pilha.

10- Execute o método Pop quatro vezes.

Lembre-se que as peças dos números removidos devem retornar às caixas organizadoras. Guarde-os no local correto, para facilitar a busca nas próximas utilizações.

Faça um novo registro no celular ou no computador, do elemento do topo da pilha, neste momento.

11- Faça a execução dos métodos a seguir:

Pop ();

Pop ();

Pop ();

Push (7);

Push (11);

Lembre-se de guardar todos os elementos removidos nos locais corretos, nas caixas organizadoras.

Faça o registro no celular ou computador do elemento do topo da pilha, após as modificações. Também informe no registro o tamanho da pilha, ou seja, a quantidade de elementos que ela contém.

Conclusão

Ao final da atividade, questione o aluno sobre suas impressões sobre o uso do material. Se ele não souber braille, indique o estudo, mesmo que bem básico, para que ele consiga memorizar a escrita, pelo menos, dos números no material tátil.

Peça para ele guardar o material na caixa novamente, com cuidado, e o instrua a treinar em casa. Para isso, passe alguns exercícios com Pilhas ou vetores, para que ele possa treinar as atividades com o material tátil e ficar mais familiarizado com seu uso, e se acostumando a sempre deixar os números organizados nas caixas organizadoras.

Ressalte que nem sempre será necessário usar o material completo com a grande base de 16 folhas. Às vezes uma única base de 8 folhas pode ser o suficiente. O aluno poderá organizar as peças de outra forma, caso prefira, mas sempre deverá deixar claro ao professor a sua lógica de organização. Com por exemplo, iniciar o preenchimento de um vetor no nível com 4 folhas, e depois continuar no nível logo abaixo, como se fosse uma única linha reta. Assim, não precisaria montar toda a estrutura que exigiria uma superfície maior.

Sugira ao aluno tentar montar a mesma pilha da atividade proposta utilizando apenas uma base de 8 folhas. Peça que ele grave um vídeo ou explique na próxima aula o processo desenvolvido.

Envie ao aluno outra sequência de números, em um documento ou mensagem no formato digital, como e-mail, documento de texto editável, PDF Acessível ou bloco de notas, e peça que ele realize as atividades propostas com a estrutura Pilha, desta sequência didática.

Avaliação

O professor deverá avaliar os registros feitos pelo aluno no celular ou computador, em documento de texto ou semelhante. O aluno deverá ter acertado sobre os elementos do topo da pilha e seu tamanho.

Analise os resultados dos registros feitos sobre as atividades passadas para casa, com o intuito de familiarização com o material. Se o aluno tiver condições de filmar a execução da atividade, peça a filmagem, pelo menos dos momentos que ele manipula o material ao executar algum passo proposto nesta sequência, para avaliar o uso do material, e pensar em melhores direcionamentos, caso necessário.

Se tiver passado o exercício para casa, analise se o aluno conseguiu montar a estrutura com as fotos ou filmagens, ou pelo menos as informações registradas, como o topo da pilha, quando pedido durante as atividades da sequência, a quantidade de elementos quando executa os métodos solicitados etc.

Procure perceber, nos eventuais erros, se o motivo foi dificuldades em utilizar o material tátil, falta de compreensão das atividades propostas ou pequenos erros de desatenção ao executar os métodos.

FINALIZAÇÃO DA SEQUÊNCIA

O aluno deve ter conseguido montar a base de 16 folhas, organizar os números nas caixas organizadoras e construir a Pilha como orientado na sequência. Ele deve conseguir enviar os registros ao professor com os resultados das atividades realizadas em casa.

Caso o discente tenha dificuldades na organização dos números, indica-se a ele fazer alguma formação ou estudar um pouco sobre o básico de um caractere braille. Conhecer como o caractere é escrito irá facilitar a memorização, e, consequentemente, aumentará consideravelmente a agilidade na hora de identificar os números nas peças, e guardá-los nas caixas organizadoras.

Perceba as dificuldades do aluno na aula seguinte. Se é na montagem das bases, se é na identificação ou organização das peças numéricas, ou se é no próprio conteúdo de Pilha. Isso pode ser trabalhado com mais detalhamento, reutilizando esta sequência didática, nos passos referentes às dificuldades do discente. Se quiser, pode trabalhar com uma pilha contendo menos elementos, para facilitar a compreensão, e ir aumentando a quantidade aos poucos.

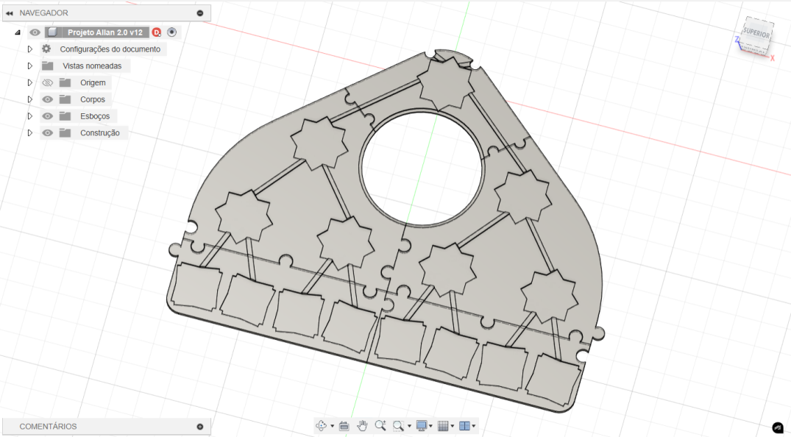
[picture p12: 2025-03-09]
Material Tátil/BliDS - Versão 4/Para impressão 3D/1- Imagem Base 8F - BlinDS.webp

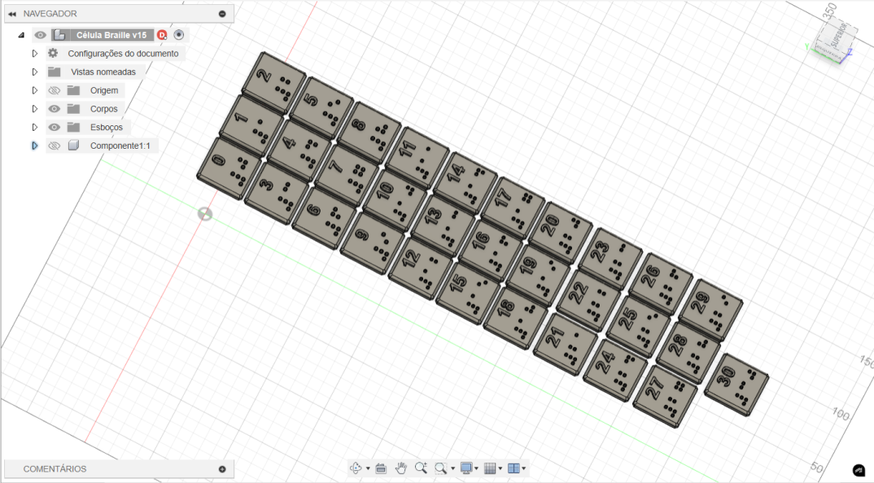
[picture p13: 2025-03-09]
Material Tátil/BliDS - Versão 4/Para impressão 3D/4- Imagem Peça Numérica.webp

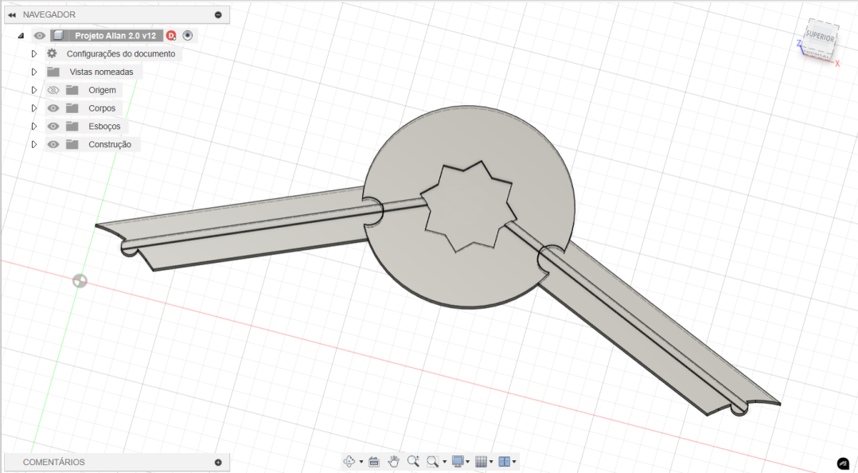
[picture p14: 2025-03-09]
Material Tátil/BliDS - Versão 4/Para impressão 3D/2- Imagem Raiz Conectora.webp

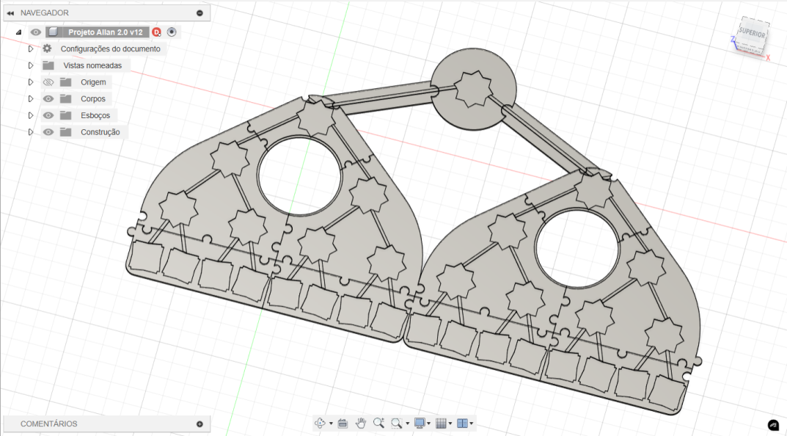
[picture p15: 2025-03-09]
Material Tátil/BliDS - Versão 4/Para impressão 3D/0- Imagem Base 16F BlinDS.webp

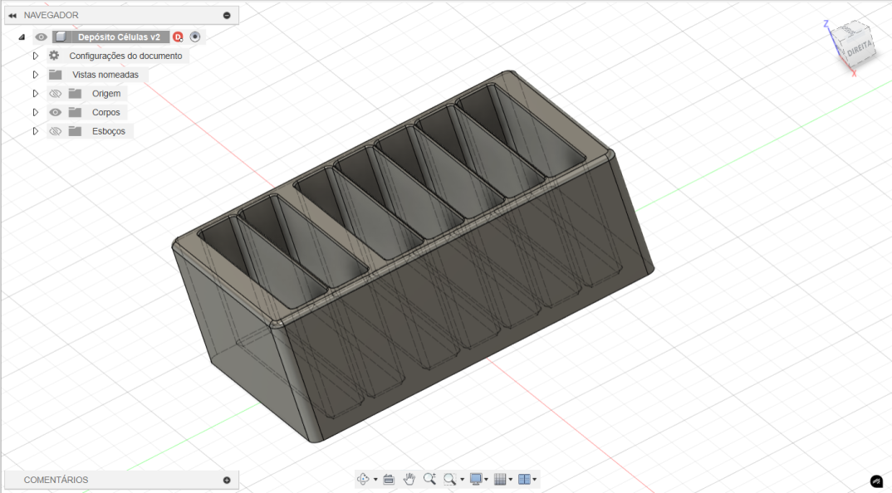
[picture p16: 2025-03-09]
Material Tátil/BliDS - Versão 4/Para impressão 3D/3- Imagem Caixa Organiz.webp

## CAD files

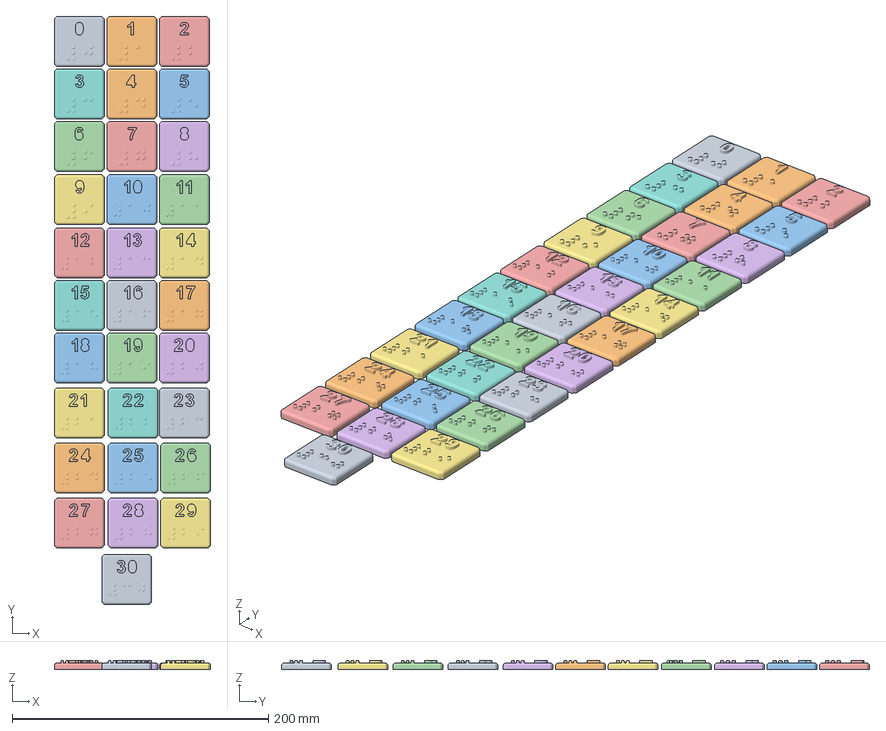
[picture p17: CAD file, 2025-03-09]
Material Tátil/BliDS - Versão 4/Para impressão 3D/4- Peças Numéricas - BlinDS.3mf
122.0 x 459.0 x 7.00 mm
Célula 0
Célula 1
Célula 10
Célula 11
Célula 12
Célula 13
Célula 14
Célula 15
Célula 16
Célula 17
Célula 18
Célula 19
Célula 2
Célula 20
Célula 21
Célula 22
Célula 23
Célula 24
Célula 25
Célula 26
Célula 27
Célula 28
Célula 29
Célula 3
Célula 30
Célula 4
Célula 5
Célula 6
Célula 7
Célula 8
Célula 9

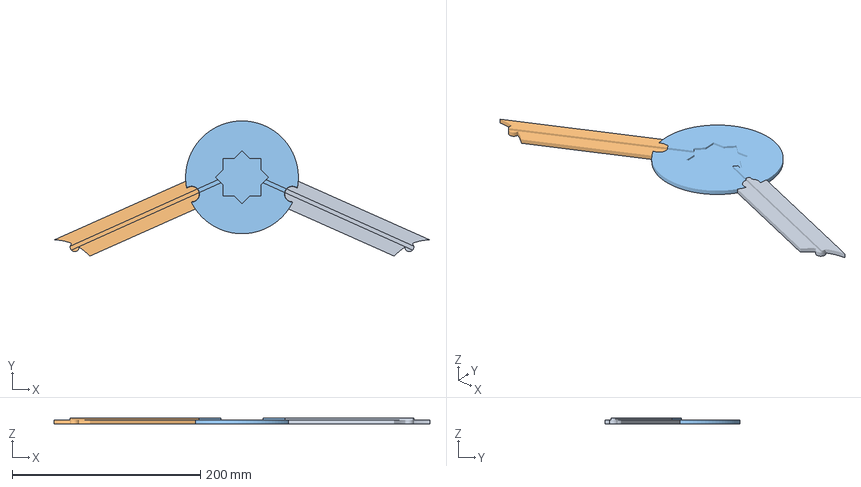
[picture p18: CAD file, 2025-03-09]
Material Tátil/BliDS - Versão 4/Para impressão 3D/2- Raiz Conectora - Arquivo Completo.3mf
400.0 x 143.7 x 6.00 mm
Conexão Direita
Conexão Esquerda
Círculo

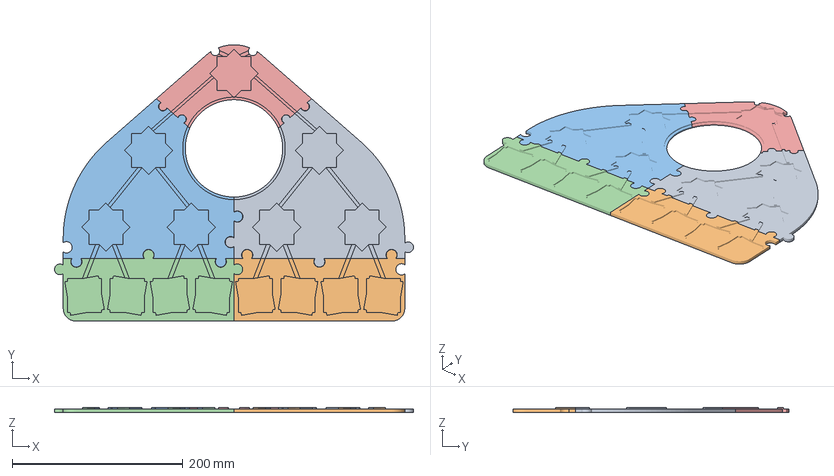
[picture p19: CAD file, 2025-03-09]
Material Tátil/BliDS - Versão 4/Para impressão 3D/1- Base de 8 Folhas - Arquivo Completo.3mf
420.4 x 323.6 x 6.00 mm
Direita 3 Células
Direita 4 Células
Esquerda 3 Células
Esquerda 4 Células
Topo 1

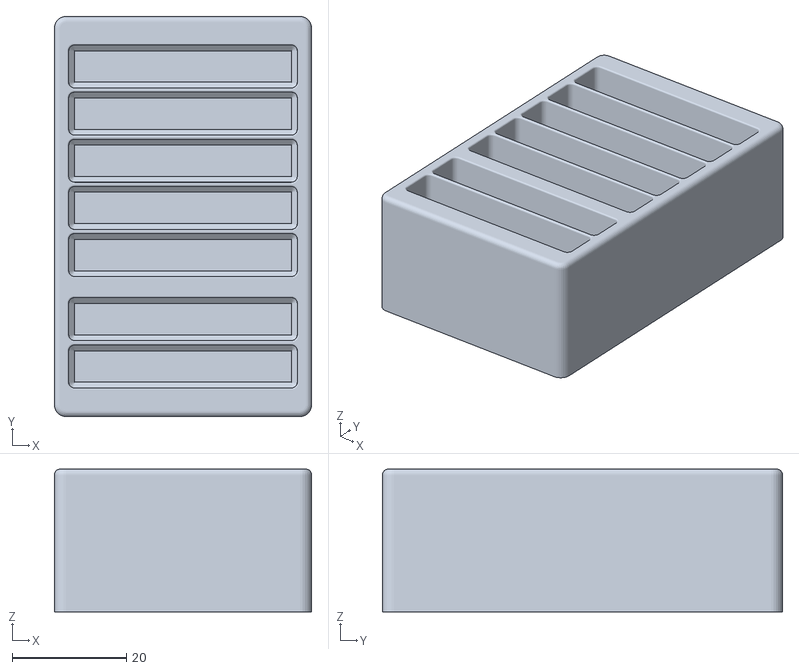
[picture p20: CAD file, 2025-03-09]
Material Tátil/BliDS - Versão 4/Para impressão 3D/3- Caixa organizadora.stl
45.0 x 70.0 x 25.0

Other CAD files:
Material Tátil/BliDS - Versão 4/Editáveis/1 e 2- Base 8F e Raiz.f3d
Material Tátil/BliDS - Versão 4/Editáveis/3- Caixa Organizadora.f3d
